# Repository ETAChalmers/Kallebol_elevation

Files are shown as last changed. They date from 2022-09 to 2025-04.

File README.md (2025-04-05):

# OLD deprecated Kallebol_elevation
This project has been abandoned and is not in use

Microcontroller and code for controlling elevation of kallebolen.

The microcontroller communicates via USB.

## Communication interface
 
### commandlist

 - ELEVATION HOME START    - Start homing of the elevationcontroller, this resets the current position
 - ELEVATION HOME STOP     - Stop homing
 - ELEVATION SET *Integer* - Set current position
 - ELEVATION GOTO *Integer* - Set current target position
 - ELEVATION STOP          - kind of a E-stop to the elevation controller, the onboard motor driver should not output any voltage
 - ELEVATION STOP RESET    - turn off the stop state
 - ELEVATION GET POSITION  - returns the current position of the controller
 - ELEVATION GET TARGET    - returns the target position of the controller
 - ELEVATION GET FLAGS     - returns the states of the controller
 - ELEVATION GET ALL       - returns all of the states and positions
 - LOAD LOAD1 [ON/OFF]     - turn on/off load 1
 - LOAD LOAD2 [ON/OFF]     - turn on/off load 2
 - LED ONBOARD [ON/OFF]    - turn on/off the MCUs onboard LED
 - LED PCB0 [ON/OFF]       - turn on/off LED 0 on the PCB
 - LED PCB1 [ON/OFF]       - turn on/off LED 0 on the PCB
 - LED PCB2 [ON/OFF]       - turn on/off LED 0 on the PCB
 - LED PCB3 [ON/OFF]       - turn on/off LED 0 on the PCB
 - RFSWITCH    (TBD)

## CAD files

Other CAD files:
circuit_files/KiCad-RP-Pico-main/KiCad-RP-Pico-main/SketchUp Model/Pico.skp

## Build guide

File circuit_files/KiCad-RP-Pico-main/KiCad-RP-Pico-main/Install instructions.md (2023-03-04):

# Install instructions

## 1. Copy the files locally

Copy the `RP-Pico Libraries` folder wherever you like on your computer.

## 2. Install the Raspberry Pi Pico board schema symbol

Use the `KiCad | Preferences | Manage Symbol Libraries...` command to manage the symbol library:



then select the global tab and click on the folder button:



navigate to the `RP-Pico Libraries` folder, select the `MCU_RaspberryPi_and_Boards.kicad_sym` file and open it:



et voilà, the first step is completed:



You can now close the symbol libraries manager window.

## 3. Install the Raspberry Pi Pico board footprint

You can use a similar approach to add the footprint to the footprint libraries manager, but I've found some issues that I've solved using the footprint editor, so here are the steps I suggest you to follow:

Open the footprint editor



wait for the footprints to load... then use the `File | Add Library` command:



confirm the `Global` choice:



and select the `MCU_RaspberriPi_and_Boards.pretty` folder (yes, the folder represent a footprint library on KiCad):



Now the library is installed on KiCad with the Raspberry Pi Pico footprint (double click on it to see it on the editor pane):



Don't close the windows as the next step start from here.

## 4. Install the Raspberry Pi Pico board footprint 3D visual

If not already open, open the the footprint editor

symbol library manager

double click on the `RPi_Pico_SMD_TH` footprint from the `MCU_RaspberriPi_and_Boards` library and then click on the `Footprint properties` icon:



In the footprint properties window, first select the `3D Settings` tab. Please note that the preview shows only the PCB board with the footprint added on step 3, without any 3D representation of the Raspberry Pi Pico board. Now click on the folder icon to add the 3D model:



Navigate to the `RP-Pico Libraries` folder, select the `Pico.wrl` file and wait until the model is shown in the right panel, then confirm with OK:



The model is already scaled and translated to match the footprint:



now close the `Footprint Properties` window, and the `Footprint Editor`, obviously saving the changes.

## Conclusion

Now that you've installed the schema and footprint and added the 3D model to the footprint, you can use the Raspberry Pi Pico board on your KiCad projects.

I've also added a test KiCad Project on the `Test` folder, that you can use to see an example of it.

Have fun!

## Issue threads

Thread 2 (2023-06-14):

Serial server input/output error

TheMotonaut, 2023-06-14:
Sending results in Input/output error on serial server on Kallebol

`ERROR:root:[Errno 5] Input/output error`

restarting the server results in:

`ERROR:root:Could not open serial port /dev/ttyACM0: [Errno 2] could not open port /dev/ttyACM0: [Errno 2] No such file or directory: '/dev/ttyACM0'`

 This caused by the device switching port from ttyACM0 to ttyACM1. Occasionally it switches back to ACM0.

TheMotonaut, 2023-06-14:
Using screen kicks user out when sending data. Likely caused by the same error

ertex, 2023-07-14:
skill issue

mateuszdrwal, 2023-07-14:
> This caused by the device switching port from ttyACM0 to ttyACM1. Occasionally it switches back to ACM0.

Use /dev/serial instead, that way you won't be jumpscared by the device switching serial ports

Closed 2023-07-14.

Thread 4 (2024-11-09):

Simon geböhlen på att string är svåra 😭 så data sickas tillbaka som HEX

ertex, 2024-11-09:
data  frame
Startsequence 6 bytes 0x58 0x58 0x58 0x58 0x58 0x58 (ASCII XXXXXX)
datapackage length 2 bytes (inkl startsequence length)
content of responce
accumulated checksum, 1byte (not including start/stop sequence)
Stopsequence 6bytes 0x38 0x3D 0x3D 0x3D 0x3D 0x44 (ASCII 8====D)

If a invalid command is recived, return error in content part

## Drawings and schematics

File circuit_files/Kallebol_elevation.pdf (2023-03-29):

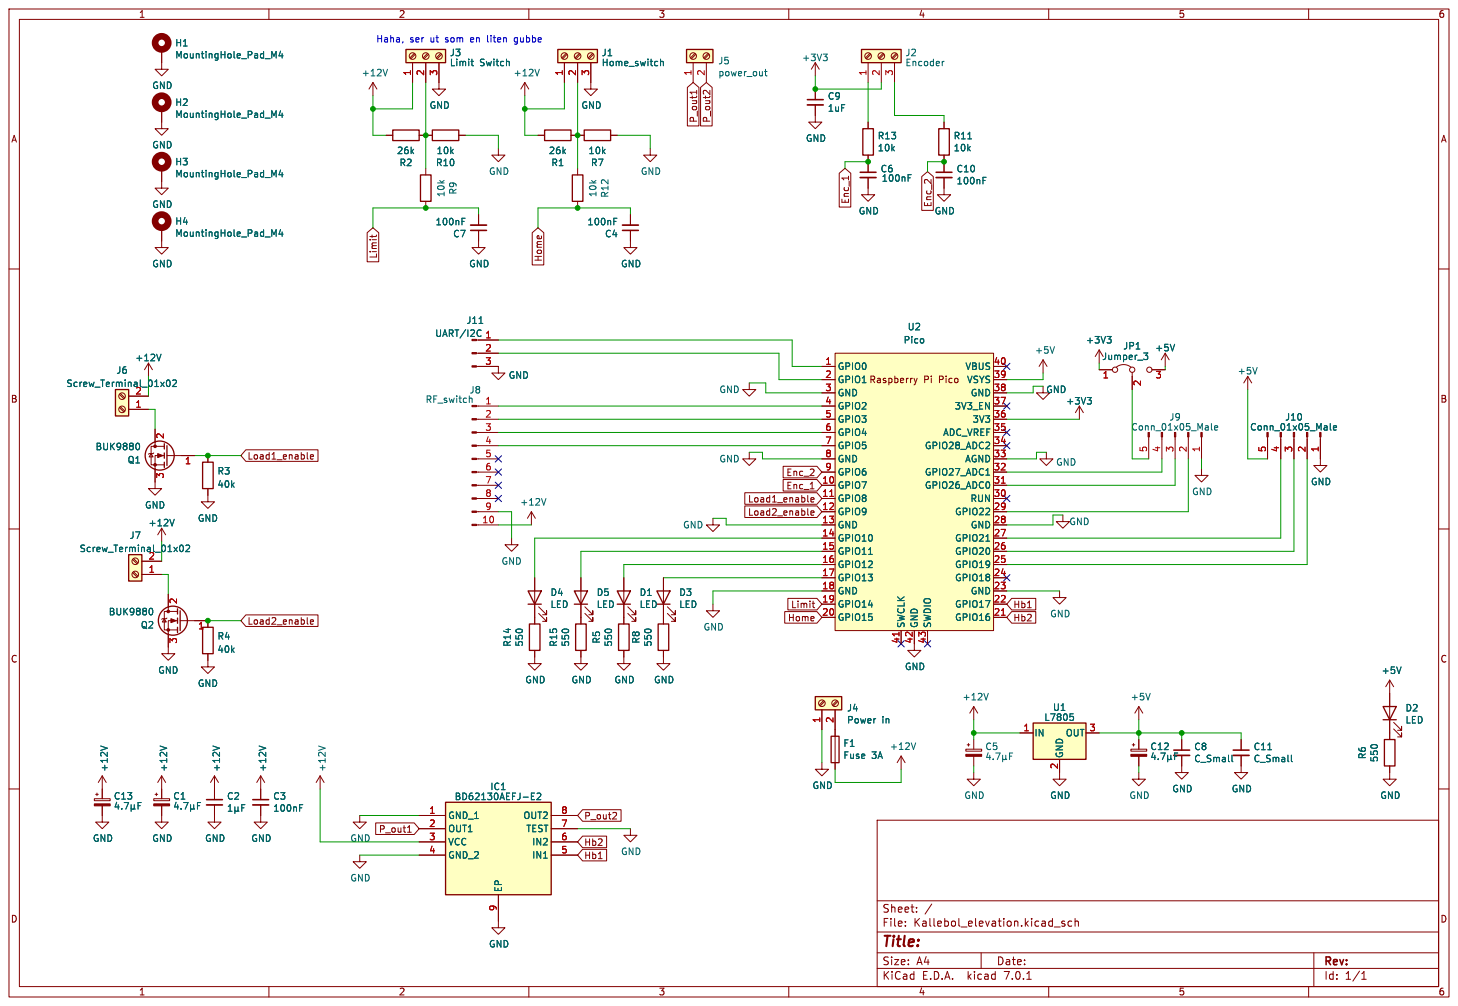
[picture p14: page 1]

H3 MountingHole_Pad_M4 H4 MountingHole_Pad_M4 GND
100nF GND GND GND GND

2 3 Q2 BUK9880 Raspberry Pi Pico GPIO0 1 GPIO7 10 GPIO8 11 GPIO9 12 GND 13 GPIO10 14 GPIO11 15 GPIO12 16 GPIO13 17 GND 18 GPIO14 19 GPIO1 2 GPIO15 20 GPIO16 21 GPIO17 22 GND 23 GPIO18 24 GPIO19 25 GPIO20 26 GPIO21 27 GND 28 GPIO22 29 GND 3 RUN 30 GPIO26_ADC0 31 GPIO27_ADC1 32 AGND 33 GPIO28_ADC2 34 ADC_VREF 35

LED GND R8 550 GND R15 550 GND

9 GND GND R8 550 GND R15 550 GND

2Power in F1Fuse 3A GND GND GND

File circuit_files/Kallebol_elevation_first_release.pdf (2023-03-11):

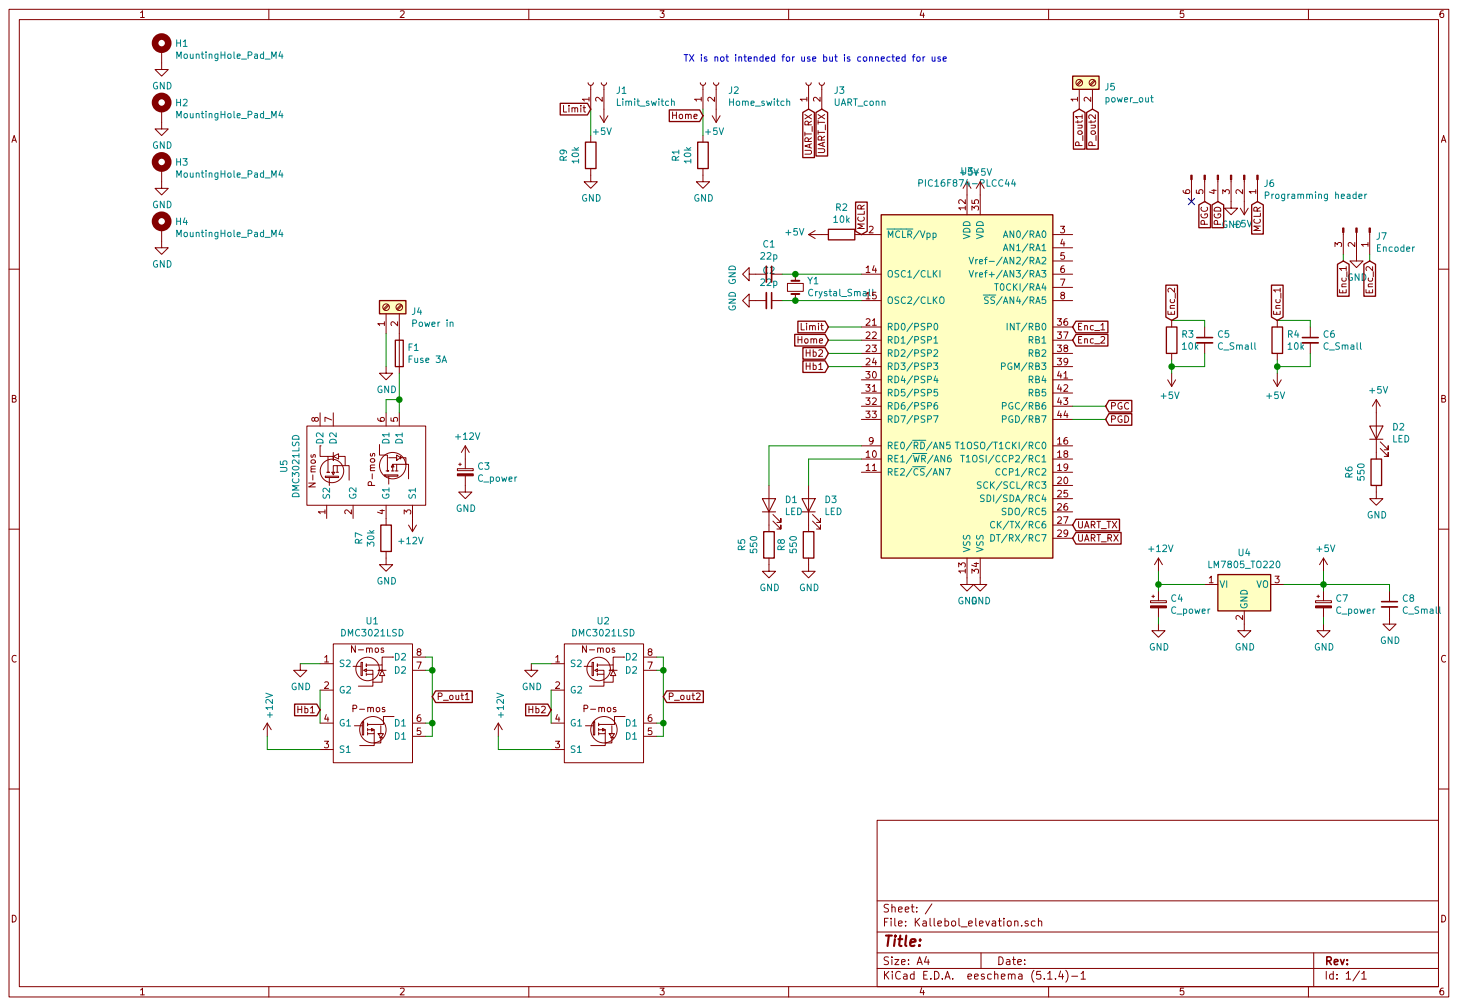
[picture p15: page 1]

TX is not intended for use but is connected for use

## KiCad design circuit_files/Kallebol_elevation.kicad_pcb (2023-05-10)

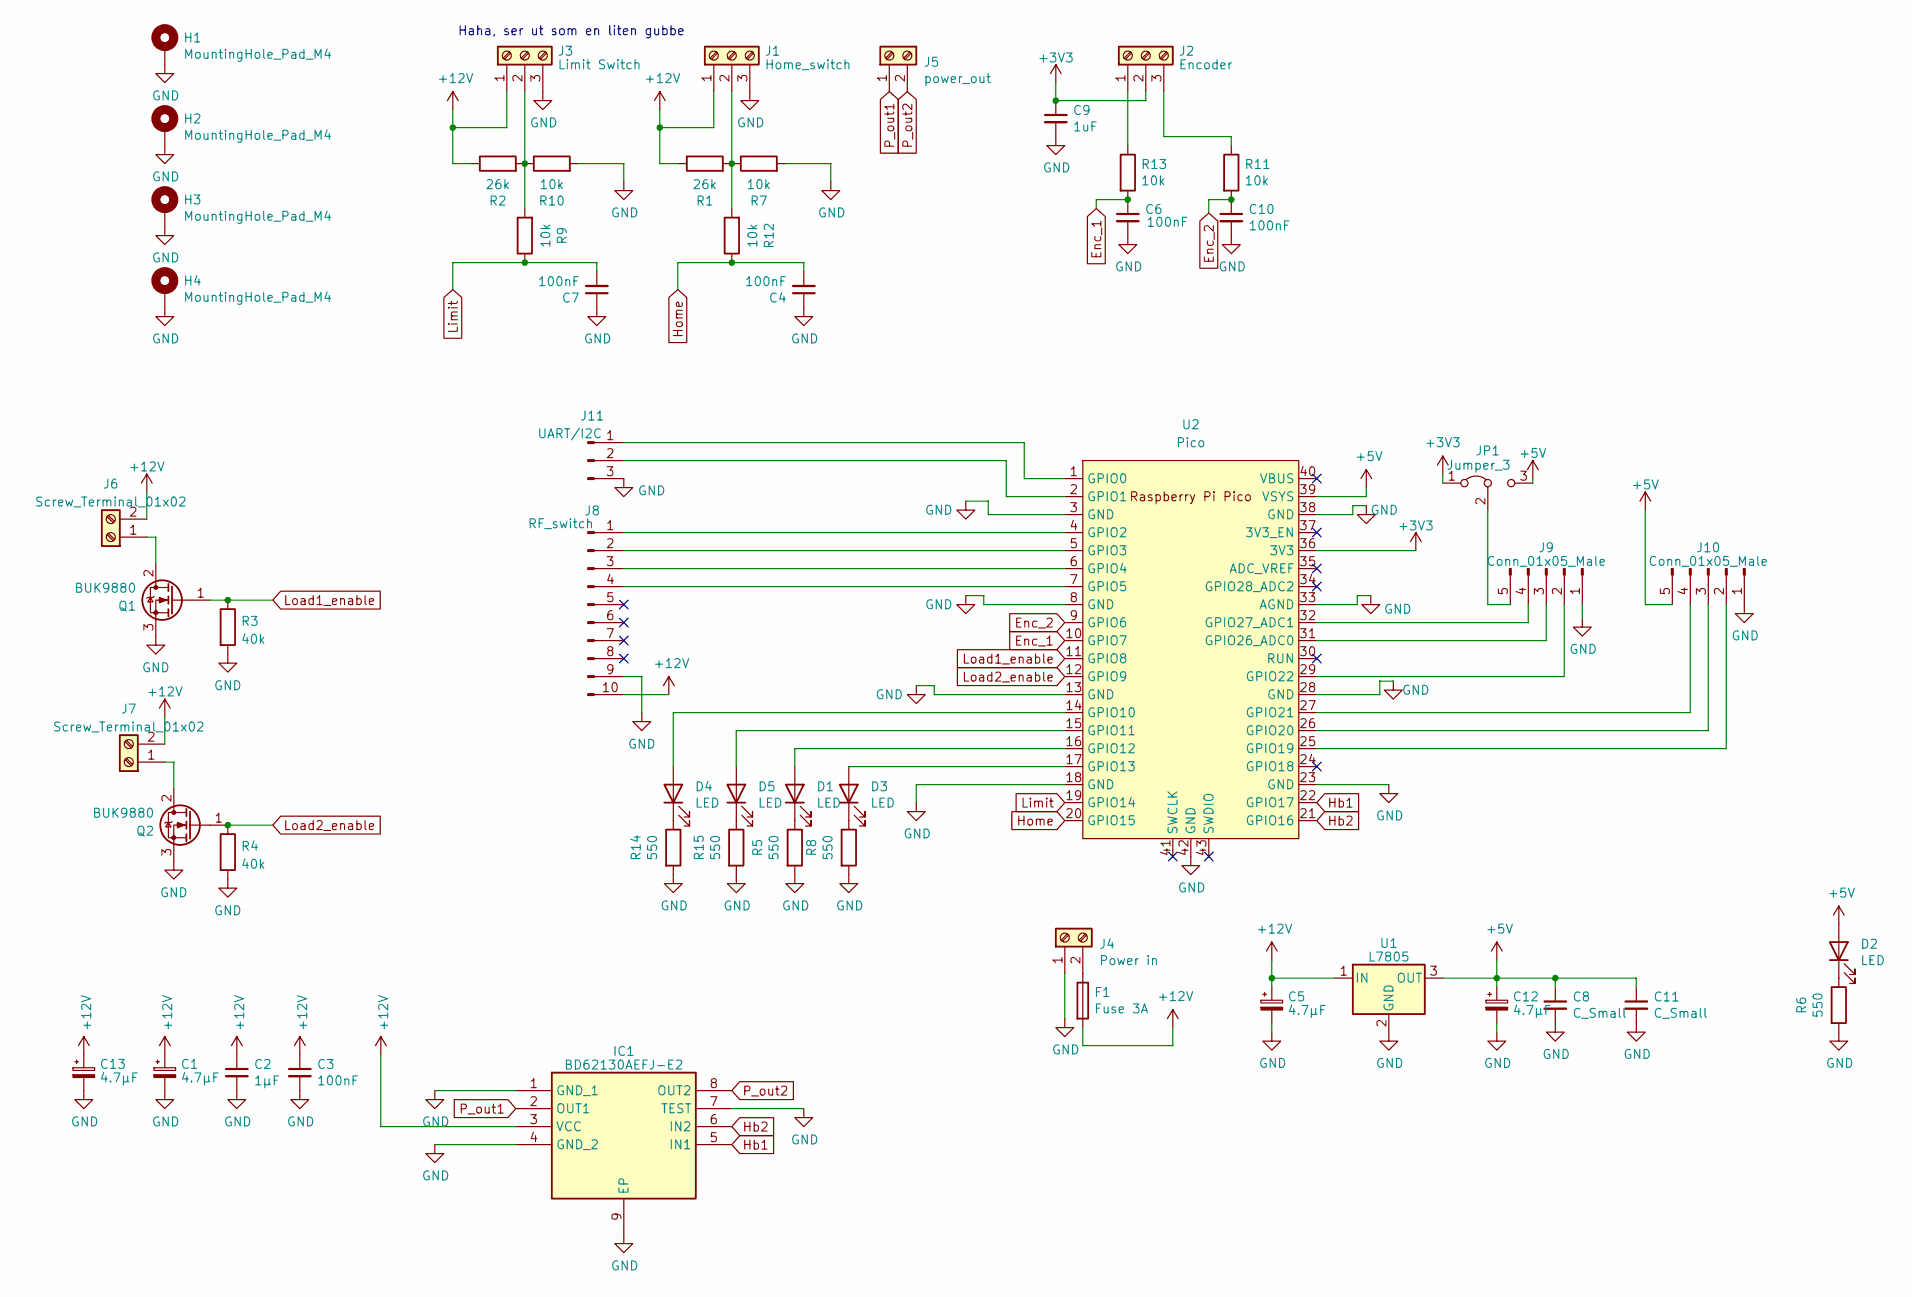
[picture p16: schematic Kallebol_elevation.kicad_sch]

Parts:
C1, C5, C12, C13: 4.7µF; CP_Elec_10x10
C2: 1µF; C_0603_1608Metric_Pad1.08x0.95mm_HandSolder
C3, C4, C6, C7, C10: 100nF; C_0603_1608Metric_Pad1.08x0.95mm_HandSolder
C8, C11: C_Small; C_0603_1608Metric_Pad1.08x0.95mm_HandSolder
C9: 1uF; C_0603_1608Metric_Pad1.08x0.95mm_HandSolder
D1, D2, D3, D4, D5: LED; LED_0603_1608Metric
F1: Fuse 3A; Fuseholder_Cylinder-5x20mm_Wuerth_696103101002-SMD_Horizont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
H1, H2, H3, H4: MountingHole_Pad_M4; MountingHole_4.3mm_M4_Pad
IC1: BD62130AEFJ-E2; SOIC127P600X100-9N; Mouser Part Number 755-BD62130AEFJ-E2
J1: Home_switch; TerminalBlock_Phoenix_MKDS-1,5-3_1x03_P5.00mm_Horizontal
J2: Encoder; TerminalBlock_Phoenix_MKDS-1,5-3_1x03_P5.00mm_Horizontal
J3: Limit Switch; TerminalBlock_Phoenix_MKDS-1,5-3_1x03_P5.00mm_Horizontal
J4: Power in; TerminalBlock_bornier-2_P5.08mm
J5: power_out; TerminalBlock_bornier-2_P5.08mm
J6, J7: Screw_Terminal_01x02; TerminalBlock_bornier-2_P5.08mm
J8: RF_switch; PinSocket_1x10_P2.54mm_Vertical
J9, J10: Conn_01x05_Male; PinSocket_1x05_P2.54mm_Vertical
J11: UART/I2C; PinSocket_1x03_P2.54mm_Vertical
JP1: Jumper_3; PinSocket_1x03_P2.54mm_Vertical
Q1, Q2: BUK9880; SOT-223-3_TabPin2
R1, R2: 26k; R_0603_1608Metric_Pad0.98x0.95mm_HandSolder
R3, R4: 40k; R_0603_1608Metric_Pad0.98x0.95mm_HandSolder
R5, R6, R8, R14, R15: 550; R_0603_1608Metric_Pad0.98x0.95mm_HandSolder
R7, R9, R10, R11, R12, R13: 10k; R_0603_1608Metric_Pad0.98x0.95mm_HandSolder
U1: L7805; SOT-223-3_TabPin2
U2: Pico; RPi_Pico_SMD_TH

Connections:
+3V3: C9.1, J2.2, JP1.1 (A), U2.36 (3V3)
+5V: C8.1, C11.1, C12.1, D2.2 (A), J10.5, JP1.3 (B), U1.3 (OUT), U2.39 (VSYS)
+12V: C1.1, C2.1, C3.1, C5.1, C13.1, F1.2, IC1.3 (VCC), J1.1, J3.1, J6.2, J7.2, J8.10, R1.1, R2.1, U1.1 (IN)
Enc_1: C6.1, R13.2, U2.10 (GPIO7)
Enc_2: C10.1, R11.2, U2.9 (GPIO6)
GND: C1.2, C2.2, C3.2, C4.1, C5.2, C6.2, C7.1, C8.2, C9.2, C10.2, C11.2, C12.2, C13.2, H1.1, H2.1, H3.1, H4.1, IC1.1 (GND_1), IC1.4 (GND_2), IC1.7 (TEST), IC1.9 (EP), J1.3, J3.3, J4.1, J8.9, J9.1, J10.1, J11.3, Q1.3 (S), Q2.3 (S), R3.2, R4.2, R5.2, R6.2, R7.2, R8.2, R10.2, R14.2, R15.2, U1.2 (GND), U2.3 (GND), U2.8 (GND), U2.13 (GND), U2.18 (GND), U2.23 (GND), U2.28 (GND), U2.33 (AGND), U2.38 (GND), U2.42 (GND)
Hb1: IC1.5 (IN1), U2.22 (GPIO17)
Hb2: IC1.6 (IN2), U2.21 (GPIO16)
Home: C4.2, R12.1, U2.20 (GPIO15)
Limit: C7.2, R9.1, U2.19 (GPIO14)
Load1_enable: Q1.1 (G), R3.1, U2.11 (GPIO8)
Load2_enable: Q2.1 (G), R4.1, U2.12 (GPIO9)
unnamed: D1.2 (A), U2.16 (GPIO12)
unnamed: D1.1 (K), R5.1
unnamed: D2.1 (K), R6.1
unnamed: D3.2 (A), U2.17 (GPIO13)
unnamed: D3.1 (K), R8.1
unnamed: D4.2 (A), U2.14 (GPIO10)
unnamed: D4.1 (K), R14.1
unnamed: D5.2 (A), U2.15 (GPIO11)
unnamed: D5.1 (K), R15.1
unnamed: J1.2, R1.2, R7.1, R12.2
unnamed: J2.1, R13.1
unnamed: J2.3, R11.1
unnamed: J3.2, R2.2, R9.2, R10.1
unnamed: F1.1, J4.2
unnamed: J6.1, Q1.2 (D)
unnamed: J7.1, Q2.2 (D)
unnamed: J8.1, U2.4 (GPIO2)
unnamed: J8.2, U2.5 (GPIO3)
unnamed: J8.3, U2.6 (GPIO4)
unnamed: J8.4, U2.7 (GPIO5)
unnamed: J9.2, U2.29 (GPIO22)
unnamed: J9.3, U2.31 (GPIO26_ADC0)
unnamed: J9.4, U2.32 (GPIO27_ADC1)
unnamed: J9.5, JP1.2 (C)
unnamed: J10.2, U2.25 (GPIO19)
unnamed: J10.3, U2.26 (GPIO20)
unnamed: J10.4, U2.27 (GPIO21)
unnamed: J11.1, U2.1 (GPIO0)
unnamed: J11.2, U2.2 (GPIO1)
P_out1: IC1.2 (OUT1), J5.1
P_out2: IC1.8 (OUT2), J5.2

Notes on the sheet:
Haha, ser ut som en liten gubbe

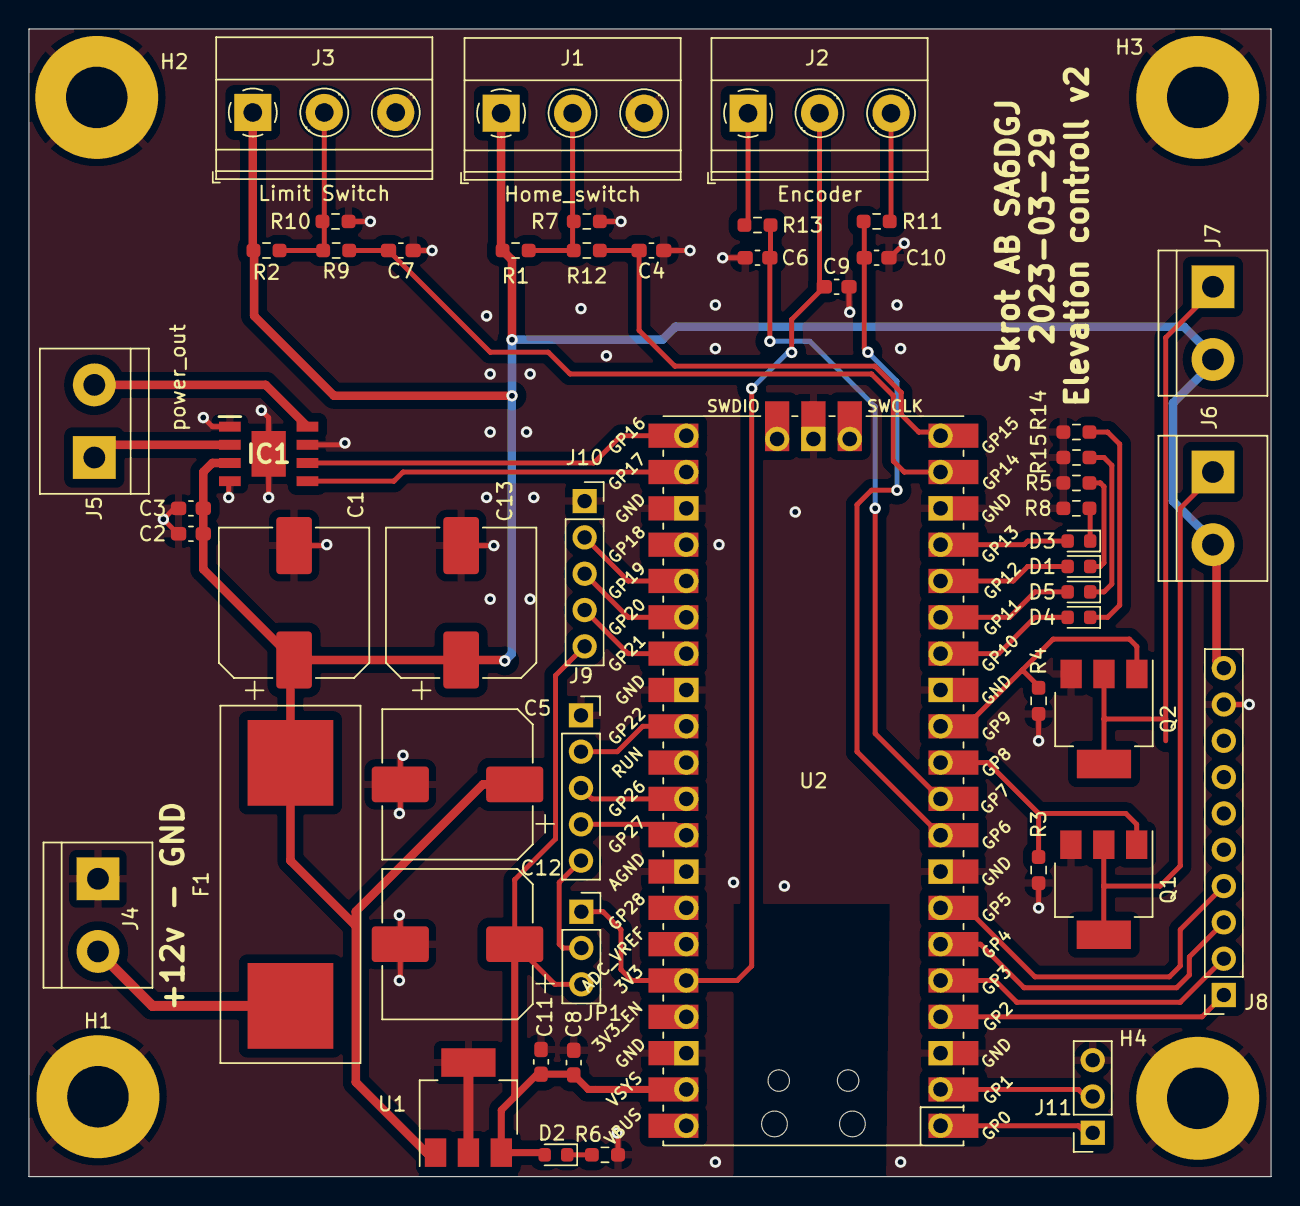
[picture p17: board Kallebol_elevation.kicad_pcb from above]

Board: 2 copper layers, 86.9 x 80.3 mm, 55 parts (0 on the bottom side), 43 nets.

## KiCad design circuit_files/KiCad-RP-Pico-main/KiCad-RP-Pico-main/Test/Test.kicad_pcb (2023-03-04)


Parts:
J1, J2: Conn_01x20; PinSocket_1x20_P1.00mm_Vertical
J3: Conn_01x03; PinSocket_1x03_P1.00mm_Vertical
U1: Pico; RPi_Pico_SMD_TH

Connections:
GND: J1.3, J1.8, J1.13, J1.18, J2.3, J2.13, J2.18, J3.2, U1.3 (GND), U1.8 (GND), U1.13 (GND), U1.18 (GND), U1.23 (GND), U1.28 (GND), U1.38 (GND), U1.42 (GND)
unnamed: J1.1, U1.1 (GPIO0)
unnamed: J1.2, U1.2 (GPIO1)
unnamed: J1.4, U1.4 (GPIO2)
unnamed: J1.5, U1.5 (GPIO3)
unnamed: J1.6, U1.6 (GPIO4)
unnamed: J1.7, U1.7 (GPIO5)
unnamed: J1.9, U1.9 (GPIO6)
unnamed: J1.10, U1.10 (GPIO7)
unnamed: J1.11, U1.11 (GPIO8)
unnamed: J1.12, U1.12 (GPIO9)
unnamed: J1.14, U1.14 (GPIO10)
unnamed: J1.15, U1.15 (GPIO11)
unnamed: J1.16, U1.16 (GPIO12)
unnamed: J1.17, U1.17 (GPIO13)
unnamed: J1.19, U1.19 (GPIO14)
unnamed: J1.20, U1.20 (GPIO15)
unnamed: J2.1, U1.40 (VBUS)
unnamed: J2.2, U1.39 (VSYS)
unnamed: J2.4, U1.37 (3V3_EN)
unnamed: J2.5, U1.36 (3V3)
unnamed: J2.6, U1.35 (ADC_VREF)
unnamed: J2.7, U1.34 (GPIO28_ADC2)
unnamed: J2.8, U1.33 (AGND)
unnamed: J2.9, U1.32 (GPIO27_ADC1)
unnamed: J2.10, U1.31 (GPIO26_ADC0)
unnamed: J2.11, U1.30 (RUN)
unnamed: J2.12, U1.29 (GPIO22)
unnamed: J2.14, U1.27 (GPIO21)
unnamed: J2.15, U1.26 (GPIO20)
unnamed: J2.16, U1.25 (GPIO19)
unnamed: J2.17, U1.24 (GPIO18)
unnamed: J2.19, U1.22 (GPIO17)
unnamed: J2.20, U1.21 (GPIO16)
unnamed: J3.1, U1.43 (SWDIO)
unnamed: J3.3, U1.41 (SWCLK)


Board: 2 copper layers, 43.0 x 65.0 mm, 4 parts (0 on the bottom side), 36 nets.

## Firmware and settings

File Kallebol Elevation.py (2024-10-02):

#Welcome to Python hell
#by yours truly, SA6DGJ
#range of movement is 1117 pulses
from machine import Pin
import select
import sys
import time
onboardled = Pin("LED", Pin.OUT)
PCB0_LED = Pin(10, Pin.OUT)
PCB1_LED = Pin(11, Pin.OUT)
PCB2_LED = Pin(12, Pin.OUT)
PCB3_LED = Pin(13, Pin.OUT)
LOAD1_pin = Pin(8, Pin.OUT)
LOAD2_pin = Pin(9, Pin.OUT)
ENC_A = Pin(6,Pin.IN,Pin.PULL_DOWN)
ENC_B = Pin(7,Pin.IN,Pin.PULL_DOWN)

Homing_pin = Pin(15,Pin.IN)
Limit_pin = Pin(14,Pin.IN)

RF1_pin = Pin(2, Pin.OUT)
RF2_pin = Pin(3, Pin.OUT)
RF3_pin = Pin(4, Pin.OUT)
RF4_pin = Pin(5, Pin.OUT)

H_bridge_1 = Pin(17, Pin.OUT) #H bridge inputs
H_bridge_2 = Pin(16, Pin.OUT)
H_bridge_1.value(0) #init as 0
H_bridge_2.value(0)

poll_obj = select.poll()
poll_obj.register(sys.stdin, select.POLLIN)

LED_blink_counter = 0

#Global values
stop = 0 # a pseudo E-stop
HW_stop = 0 # indicates that a hardware stop has been reached -1 homing switch, 1 limit switch
homeing = 0
movedir = 0 # 1 = extend, 0 = break, -1 retract
hardware_movedir = 0 # the movedir as commanded by the elevation controller, for debug purposes
setpoint_value = 0 #value from the master
encoder_value = 0  #The current position of the motor


def Encoder_callback(args):
    global encoder_value
    if ENC_B.value() == 1:
        encoder_value = encoder_value + 1
        #print_custom("I increased the counter to : " + str(encoder_value))
    else:
        encoder_value = encoder_value - 1
        #print_custom("I Decreased the counter to : " + str(encoder_value))
    time.sleep_ms(1) #debounce
    update_elevation_stage_direction()
        
def homing_callback(args):
    global HW_stop
    global encoder_value
    global homeing
    global setpoint_value
    print_custom("homeswitch reached")
    encoder_value = 0
    setpoint_value = 0
    homeing = 0
    update_stops()
    update_elevation_stage_direction()

def limit_callback(args): # this should do something to ensure that it does not pass the limit
    global HW_stop
    print_custom("limit switch reached")
    update_stops()
    update_elevation_stage_direction()
        

def LED_handler(data): #accepts splitdata
    #BEHOLD MY IF STATEMENTS!
    if (data[1] == "ONBOARD"): # Onboard the Raspberry
        if (data[2] == "ON"):
            onboardled.value(1)
        else:
            onboardled.value(0)
            
    elif (data[1] == "PCB0"):
        if (data[2] == "ON"):
            PCB0_LED.value(1)
        else:
            PCB0_LED.value(0)
            
    elif (data[1] == "PCB1"):
        if (data[2] == "ON"):
            PCB1_LED.value(1)
        else:
            PCB1_LED.value(0)
            
    elif (data[1] == "PCB2"):
        if (data[2] == "ON"):
            PCB2_LED.value(1)
        else:
            PCB2_LED.value(0)
            
    elif (data[1] == "PCB3"):
        if (data[2] == "ON"):
            PCB3_LED.value(1)
        else:
            PCB3_LED.value(0)
# END LED_handler
        
        
def LOAD_handler(data): #accepts splitdata
    if (data[1] == "LOAD1"): # Onboard the Raspberry
        if (data[2] == "ON"):
            LOAD1_pin.value(1)
        else:
            LOAD1_pin.value(0)
    elif (data[1] == "LOAD2"):
        if (data[2] == "ON"):
            LOAD2_pin.value(1)
        else:
            LOAD2_pin.value(0)

def Elevation_command_handler(data):
    global stop
    global movedir
    global homeing
    global encoder_value
    global setpoint_value
    global HW_stop
    global HWmovedir
    
    if (data[1] == "HOME"):
        if (data[2] == "START"):
            homeing = 1
        else:
            homeing = 0
    if (data[1] == "GOTO"):
        try:
            setpoint_value = int(data[2])
        except Exception as e:
            foo = []
            foo[0] = e
            foo[1] =data[3]
            print_custom(foo)
    if (data[1] == "SET"):
        try:
            encoder_value = int(data[2])
        except Exception as e:
            print_custom(e)
    if (data[1] == "STOP"):
        stop = 1
        if (data[2] == "RESET"):
            stop = 0
    if (data[1] == "GET"):
        if (data[2] == "POSITION"):
            print_custom(str(encoder_value))
        if (data[2] == "TARGET"):
            print_custom(str(setpoint_value))
        if (data[2] == "FLAGS"):
            print_custom("Homeing : " + str(homeing) + " ,Movedir : " + str(movedir) + " ,HWmovedir : " + str(hardware_movedir) + " ,Stop : " + str(stop) + " ,HW_stop : " + str(HW_stop))
        if (data[2] == "PINS"):
            foo = ["","","",""] # for some reason dynamic allocation did not work, so this is how it goes down
            foo [0] = "LOAD1 : " + str(LOAD1_pin.value()) +  " ,LOAD2 : " + str(LOAD2_pin.value()) + " ,ENC_A : " + str(ENC_A.value()) + " ,ENC_B : " + str(ENC_B.value())
            foo [1] = "Homing_pin : " + str(Homing_pin.value())  + " ,Limit_pin : " + str(Limit_pin.value())
            foo [2] = "RF1_pin " + str(RF1_pin.value()) + " ,RF2_pin " + str(RF2_pin.value())+ " ,RF3_pin " + str(RF3_pin.value())+ " ,RF4_pin " + str(RF4_pin.value())
            foo [3] = "Hbridge1 : " + str(H_bridge_1.value())  +  "Hbridge2 : " + str(H_bridge_2.value())
            print_custom(foo)
        if (data[2] ==  "ALL"):
            foo = ["","","","","","","","",""] # for some reason dynamic allocation did not work, so this is how it goes down
            foo [0] = "=====variables====="
            foo [1] = "Current position = " + str(encoder_value)
            foo [2] = "Target position = " + str(setpoint_value)
            foo [3] = "Homeing : " + str(homeing) + " ,Movedir : " + str(movedir) + " ,HWmovedir : " + str(hardware_movedir) + " ,Stop : " + str(stop) + " ,HW_stop : " + str(HW_stop)
            foo [4] = "=====pins====="
            foo [5] = "LOAD1 : " + str(LOAD1_pin.value()) +  " ,LOAD2 : " + str(LOAD2_pin.value()) + " ,ENC_A : " + str(ENC_A.value()) + " ,ENC_B : " + str(ENC_B.value())
            foo [6] = "Homing_pin : " + str(Homing_pin.value())  + " ,Limit_pin : " + str(Limit_pin.value())
            foo [7] = "RF1_pin " + str(RF1_pin.value()) + " ,RF2_pin " + str(RF2_pin.value())+ " ,RF3_pin " + str(RF3_pin.value())+ " ,RF4_pin " + str(RF4_pin.value())
            foo [8] = "Hbridge1 : " + str(H_bridge_1.value())  +  "Hbridge2 : " + str(H_bridge_2.value())
            print_custom(foo)
        
    

def command_interpreter(data):
    splitdata = data.split()
    
    #Append data to the end to ensure array is atleast 3 elements
    #yes, there probably is a better way, but c'mon.. this needs to run at like 1Hz
    splitdata.append("")
    splitdata.append("")
    splitdata.append("")
    
    if (splitdata[0] == "LED"):
        LED_handler(splitdata)
    elif (splitdata[0] == "LOAD"):
        LOAD_handler(splitdata)
    elif (splitdata[0] == "RFSWITCH"):
        print_custom("to be implemented")
    elif (splitdata[0] == "ELEVATION" or splitdata[0] == "EL"):
        Elevation_command_handler(splitdata)
    elif (splitdata[0] == "EXPANTION"):
        print_custom("to be implemented")
        
    update_elevation_stage_direction()
    
    
    
def update_elevation_stage_direction():
    global stop
    global movedir
    global encoder_value
    global setpoint_value
    global HW_stop
    global homeing

    #Default tracking mode
    if encoder_value > setpoint_value:
            movedir = 1
    elif encoder_value < setpoint_value:
            movedir = -1
    else:
            movedir = 0
    #Homing mode
    if homeing == 1:
        movedir = 1
    
        
    #Stopchecks
    if stop == 1:
        movedir = 0
    if HW_stop == -1 and movedir == 1:
        movedir = 0
    if HW_stop ==  1 and movedir ==  -1:
        movedir = 0 
            
    update_H_bridge_state()
        
        
        
def update_H_bridge_state():
    global stop
    global movedir
    global HWmovedir
    if movedir == 1:
        H_bridge_1.value(1)
        H_bridge_2.value(0)
        HWmovedir = 1
        
    elif movedir == -1:
        H_bridge_1.value(0)
        H_bridge_2.value(1)
        HWmovedir = -1
        
    else:
        H_bridge_1.value(0)
        H_bridge_2.value(0)
        HWmovedir = 0
        
    if stop == 1:
        H_bridge_1.value(0)
        H_bridge_2.value(0)
        HWmovedir = 0

def update_stops():
    global HW_stop
    global stop
    global homeing
    homing_pin_polarity = 1  #This state indicates that the switch is ACTIVE / has been reached / pressed down / in position
    limit_pin_polarity  = 1  #This state indicates that the switch is ACTIVE / has been reached / pressed down / in position
    
    if (not Homing_pin.value() == homing_pin_polarity) and HW_stop ==  -1:
        HW_stop = 0
    if (not Limit_pin.value() == homing_pin_polarity ) and HW_stop ==  1:
        HW_stop = 0
    if Limit_pin.value() == limit_pin_polarity:
        HW_stop = 1
    if Homing_pin.value() == homing_pin_polarity:
        homeing = 0
        HW_stop = -1
    if Homing_pin.value() == homing_pin_polarity and Limit_pin.value() == limit_pin_polarity:
        foo = []
        foo[0] = "ERROR both limit switches appear to have triggered at the same time"
        foo[1] = "ERROR I have pulled the E-stop, please reset before resuming operation"
        print_custom(foo)
        stop = 1


def print_custom(printdata):
    # This function takes a array of stings as input and prints it
    # A singular array works aswell
    length = 0
    length_str = ""
    try:
        if type(printdata) == type("foo"):
            # if the input is a string
            length = len(printdata) + 5 # the five extra chars are the length header and the carrige return
            if length < 9: # I deem printF as black magic and refuse to use it
                length_str = "00" + str(length)
            elif length < 99:
                length_str = "0" + str(length)
                
            print(length_str +  " " + printdata, end="\n\r")
        else:
           # if the inputdata is an array
            for st in printdata:
                length = length + len(st)
            length = length + 5
            if length < 9: # I deem printF as black magic and refuse to use it
                length_str = "00" + str(length)
            elif length < 99:
                length_str = "0" + str(length)
            print(length_str, end=" ") #Print witout newline, but with explicit space
            for st in printdata:
                if st == printdata[-1]:
                    print(st, end="\n\r")
                else:
                    print(st, end="\n")
    except Exception as e:
        print("035 ERROR in customprint function\r")

#enable IRQs
ENC_A.irq(trigger=ENC_A.IRQ_FALLING, handler=Encoder_callback)
Homing_pin.irq(trigger=Homing_pin.IRQ_RISING, handler=homing_callback)
Limit_pin.irq(trigger=Limit_pin.IRQ_RISING, handler=limit_callback)
#Infinite loop of the program
print_custom ("booted the MCU")
while True:
    update_stops()
    poll_results = poll_obj.poll(10)
    
    LED_blink_counter = LED_blink_counter + 1
    if LED_blink_counter == 10:
        PCB3_LED.value(1)
    if LED_blink_counter > 20:
        PCB3_LED.value(0)
        LED_blink_counter = 0
    
    if poll_results:
        data = sys.stdin.readline().strip()
        if data:
            print_custom(["received data: ", data])
            command_interpreter(data)
    

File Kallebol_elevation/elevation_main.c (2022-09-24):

/*
 * File:   elevation_main.c
 * Author: David Johansson
 *
 * Created on July 21, 2021, 1:19 PM
 */


 /*
  * UART communication
  * 
  * UART is done without a controll bit at 9600 Baud with 3 8-bit packets (24bit)
  * The first byte indicates what command is sent
  * The following bytes are optional and only used if a 0b1xxxxxxx command is sent,
  * A command that requires additional input
  * 
     Avalible commands
     * 0b00000000 - No operation, can be used to flush a desync, Reserved
     * 
     * 
     * 0b10000011 - Set current position accoring to the following data
     * 0b10000100 - Goto position accoring to the following data
     * 0b00000101 - Turn off LED1
     * 0b00000110 - Turn on  LED1
     * 0b00000111 - Home the elevation control
     * 0b00001000 - abort homing
     
     */


#include <xc.h>
#include <stdint.h>


#define _XTAL_FREQ 16000000 // 16'000'000Hz

#define LED1                1//PORTEbits.RE1 //Blue
#define LED1_TRIS           TRISEbits.TRISE1
#define LED2                0//PORTEbits.RE0 //Red
#define LED2_TRIS           TRISEbits.TRISE0
#define LED3                2//PORTEbits.RE2 //Yellow
#define LED3_TRIS           TRISEbits.TRISE2

#define Limit               PORTDbits.RD0
#define Home                PORTDbits.RD1

#define PW1                 PORTDbits.RD2    //PW1=1,PW2=0   Retract
#define PW1_TRIS            TRISDbits.TRISD2
#define PW2                 PORTDbits.RD3    //PW1=0,PW2=1   Extend
#define PW2_TRIS            TRISDbits.TRISD3
#define PW_port             PORTD
#define Encode_Int_pin      PORTBbits.RB0
#define Encode_dir          PORTBbits.RB1
#define Encode_dir_TRIS     TRISBbits.TRISB1

#define bitset(var, bitno) ((var) |= 1UL << (bitno))
#define bitclr(var, bitno) ((var) &= ~(1UL << (bitno)))

#pragma config FOSC = XT        // Oscillator Selection bits (RC oscillator)
#pragma config WDTE = OFF        // Watchdog Timer Enable bit (WDT enabled)
#pragma config PWRTE = OFF      // Power-up Timer Enable bit (PWRT disabled)
#pragma config CP = OFF         // FLASH Program Memory Code Protection bits (Code protection off)
#pragma config BOREN = ON       // Brown-out Reset Enable bit (BOR enabled)
#pragma config LVP = OFF        // Low Voltage ZIn-Circuit Serial Programming Enable bit (RB3 is digital I/O, HV on MCLR must be used for programming)
#pragma config CPD = OFF        // Data EE Memory Code Protection (Code Protection off)
#pragma config WRT = OFF        // FLASH Program Memory Write Enable (Unprotected program memory may not be written to by EECON control)

int16_t position = 0;
int16_t deadspace = 2;
int16_t goto_pos = 0;
uint16_t recived_data = 0;
uint8_t input_command = 0;
int8_t move_dir = 0;            //0 for standstill, -1 retrac, +1 extend
uint8_t last_enc_value = 0;

uint8_t wait_for_UART_data = 0; 
//this flag indicates what state the 16-bit data reception machine is in
uint8_t awaiting_command = 1;
uint8_t awaiting_second_byte = 0; //Used in UART to recive 16bit data package
uint8_t homing = 0; //If this flag is high, the machine will home and set the zero position.

//Using latch registers as recomended by XC8 manual 3.7.4
uint8_t PORTE_latch =0x00; 
uint8_t PORTD_latch =0x00;
//uint8_t PORTB_latch =0x00;

void latch_registers(){
    PORTE = PORTE_latch;
    PORTD = PORTD_latch;
}

void check_target(){
    
    //### Normal poitioning stuff   
    if(!homing){
        
        if((position - deadspace) > goto_pos){ 
            move_dir = -1; //retract

        }else if((position + deadspace)  < goto_pos){
            move_dir = 1; //extend

        }else{
            move_dir = 0;
        }
        
    }else{  //if homing sequence is active
        
        move_dir = -1;
    }
    
    //### Saftey features
    //Limit switches have a pullup, low == triggered
    
    if((! Home ) && move_dir == -1){ //Homing switch was hit
        move_dir = 0;
        position = 0;
        homing = 0;
        goto_pos = 0;
        
    }
    
    if((! Limit)  && move_dir == 1){
        move_dir = 0; 
    }
    
     //### Apply output depending on control state
    
    if(move_dir == 1){ //Extend
        bitset(PORTD_latch,2);
        bitclr(PORTD_latch,3);

    }else if(move_dir == -1){ //retract  
        bitset(PORTD_latch,3);
        bitclr(PORTD_latch,2);

    }else{
        bitclr(PORTD_latch,2);
        bitclr(PORTD_latch,3);
    }
}

void trans(uint8_t a){

    while(TRMT == 0){ //Ensure data is ready to be loaded
    } 
    TXREG=a;

}

void update_machinestate(){
    //Updates state_machine state
   
    
    if(awaiting_command == 0 && wait_for_UART_data == 0){
        //If a full command has been recived
        
        if(input_command == 0b10000100){ // command to move to a absolute position
            goto_pos = recived_data;
        } else if(input_command == 0b10000011){ // command to set the current position
            position = recived_data;  
        }
        awaiting_command = 1;
        recived_data = 0;
        wait_for_UART_data = 0;
        input_command = 0;

    }
    
    
    if(input_command && awaiting_command){
        bitclr(PORTE_latch,LED2);
        //If a new command byte has been recived
        
        //trans(input_command); //For some reason the TX wont work,
        //The MCU hangs when loading data into TXREG
        
        if(input_command & 0b10000000){
            //If the recived command requires additional data to execute
            awaiting_command = 0;
            wait_for_UART_data = 1;
            return;

        //If the command does not require additional data
        } else if(input_command == 0b00000111) { //Command to home the device
            homing = 1;
            
        } else if(input_command == 0b00001000) { //Command to home the device
            homing = 0;
                
        } else if(input_command == 0b00000110) { //Command to turn on LED1, useful for debug
            bitset(PORTE_latch,LED1);

        } else if(input_command == 0b00000101) { //Command to turn off LED1, useful for debug
            bitclr(PORTE_latch,LED1);
        }else{
            //Invalid command, Set status LED
            bitset(PORTE_latch,LED2);
            return;
        }
    }

   
}
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

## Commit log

2022-01-10 added circuitboard project files
    [Kallebol_elevation.kicad_pcb, Kallebol_elevation.sch]
2022-01-10 restuctuing of files
    [Kallebol_elevation.X.production.obj]
2022-01-10 added gitignore
    [Kallebol_elevation.X.production.obj]
2022-07-08 added echo on recived UART commands
2022-07-16 added the use of latchregisters to remove read-modify-write problems
    [elevation_main.c]
2022-07-16 removed TX capabilities and fixed dead-end state
    [elevation_main.c]
2022-07-16 fixed 16-bit data packeges being in the incorrect order
    [elevation_main.c]
2022-09-20 interupts on pin does not work
    [elevation_main.c]
2022-09-24 UART and goto movements working, minimum working product
2022-09-24 Fixed homing, deployable
2023-03-04 started a new revision with a raspberry pico as base
    [Kallebol_elevation.kicad_sch, Pico.skp, Test.kicad_pcb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]
2023-03-11 added symbol for DMC3021 and cleaned project files
    [Kallebol_elevation.sch]
2023-03-11 added basic driver circuit
    [Kallebol_elevation.kicad_sch]
2023-03-11 added BD62130A schematic symbol, to be used as driver circuit
2023-03-11 elevation part of the board functional
    [Kallebol_elevation.kicad_sch]
2023-03-11 merged functionality with the GPIO fanout board
    [Kallebol_elevation.kicad_sch]
2023-03-11 sch seems done
    [Kallebol_elevation.kicad_sch]
2023-03-29 layout done
    [Kallebol_elevation.kicad_pcb]
2023-03-29 added production files
    [Kallebol_elevation-B_Cu.gbl, Kallebol_elevation-B_Mask.gbs, Kallebol_elevation-B_Paste.gbp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]
2023-03-29 added PDF files
    [Kallebol_elevation.kicad_pcb]
2023-03-29 fixed issue with reversed mosfet
    [Kallebol_elevation-B_Cu.gbl, Kallebol_elevation-B_Mask.gbs, Kallebol_elevation-B_Paste.gbp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]
2023-05-10 started to implement the code for the new elevation controller
    [Kallebol_elevation.kicad_pcb]
2023-05-15 tested on hardware, encoder works
2023-06-10 Fixed syntax and made the motor move
    [Kallebol Elevation.py]
2023-06-10 fixed bug with motorcontroll not stopping
    [Kallebol Elevation.py]
2023-06-10 added option to change polarity of hardware switches
2023-06-11 Chnaged polarity of homing/limit switch
2023-06-11 fixed better debug and made it deployable
    [Kallebol Elevation.py]
2023-07-14 added custom printer function that defines message length and terminates with \r
2024-07-27 fixed spammy status messages
    [Kallebol Elevation.py]
2024-10-02 added a blinking LED of unknown speed
2024-10-02 fixed issue with ELEVATION GET ALL crashing the program
    [Kallebol Elevation.py]
